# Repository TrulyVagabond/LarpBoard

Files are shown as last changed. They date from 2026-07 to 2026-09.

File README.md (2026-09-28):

[][contributors-url]
[][forks-url]
[][stars-url]
[][issues-url]
[][license-url]

<br />
<div align="center">
  
  <h3 align="center">LarpBoard</h3>

  <p align="center">
    A Keyboard for Larpers
    <br />
    <br />
    <a href="https://github.com/TrulyVagabond/LarpBoard/blob/main/JOURNAL.md">Journal</a>
    &middot;
    <a href="https://github.com/TrulyVagabond/LarpBoard/issues">Report Bug</a>
    &middot;
    <a href="https://github.com/TrulyVagabond/LarpBoard/issues">Request Feature</a>
  </p>
</div>

## What is LarpBoard?

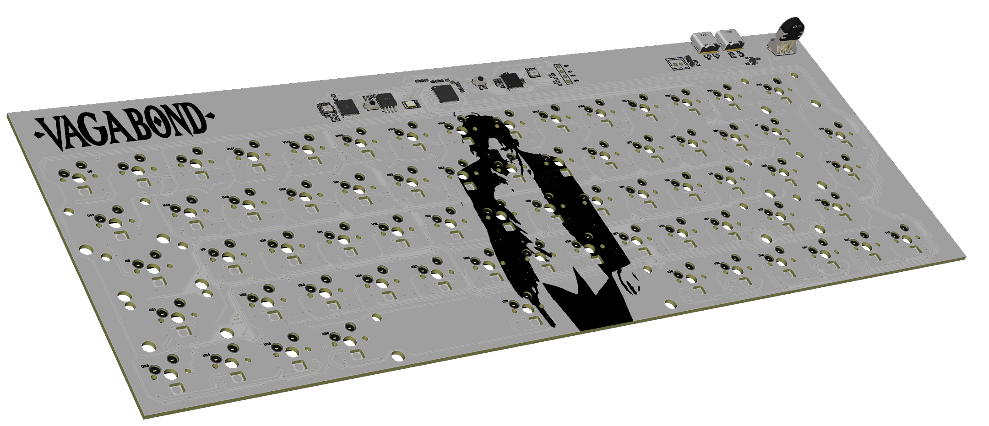
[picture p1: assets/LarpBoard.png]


LarpBoard is a 65% Keyboard Designed for Professional Larpers. Keep in mind tho that you will not get ANY girls if you have this (More MEN attraction). Build and Use this at your own Risk. Well Lets Talk about why this Keyboard will be unique and better than other Low Level Keyboards. This Keyboard Includes Kailh Hot-Swap Sockets and RGB LEDs. A 0.9inch OLED Display for CMatrix. An NFC reader cuz why not, a solenoid for sound, 2 USB-C Ports, a USB Hub Chip and the Main MCU RP2040.

### Schematics:

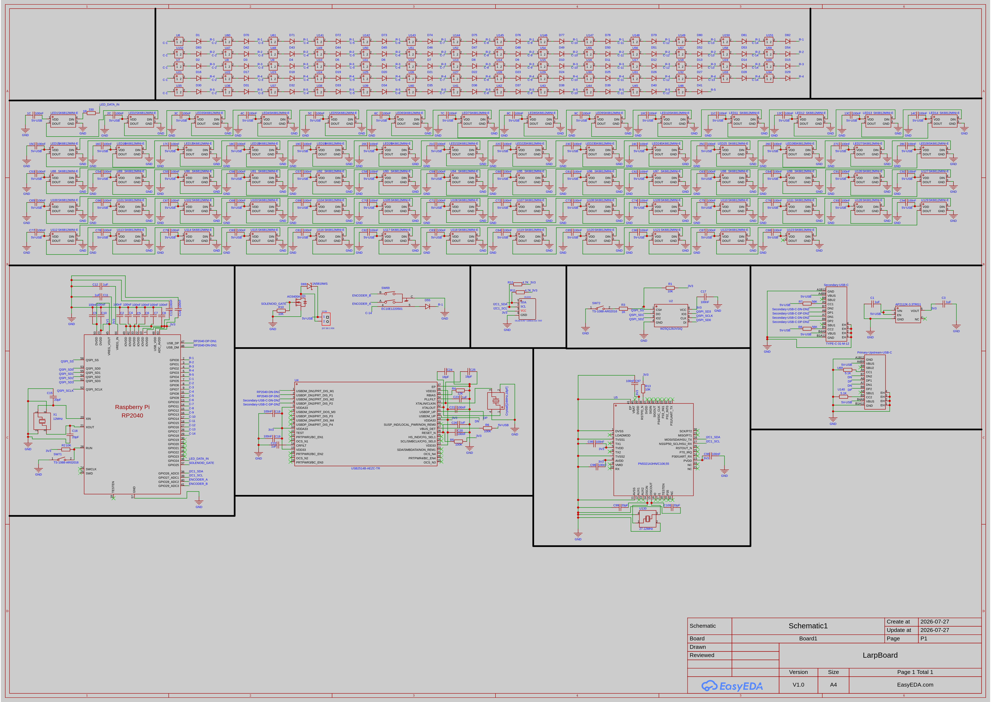
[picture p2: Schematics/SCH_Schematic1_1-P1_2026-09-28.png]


### PCB Wiring: 

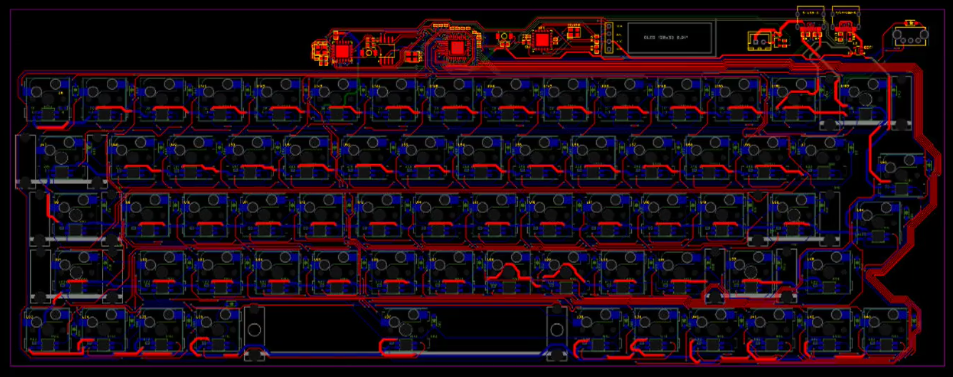
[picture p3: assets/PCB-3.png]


### Case Render:

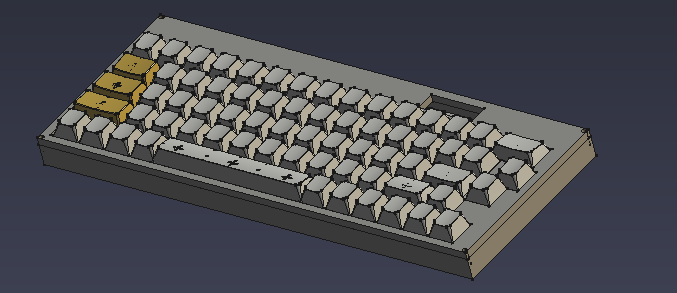
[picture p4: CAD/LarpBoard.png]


### Built With

* [][EasyEDA-url]
* [][FreeCAD-url]

## Getting Started

To get Your own LarpBoard, you need three things.

- PCB
- 3d-Printed Enclosure
- Money

### Ordering the PCB

1. Navigate to the Gerber Files in the **"Gerber"** Folder. 

2. Download the ".zip" File

3. Upload this '.zip' file to a custom PCB manufacturer (Like PCBWay, OSH Park or JLCPCB) or not if you're going to solder on your own

4. Standard Manufacturing Settings (1.6mm thickness) work Perfectly for this Board.

### 3D Printing the Enclosure

1. Navigate to the **"CAD"** folder.

2. Download the .Step File and Upload it into your Desired 3D slicing Software.

## Bills Of Materials (BOM)

| Qty | Component | Designator | Direct Source Link | Unit Cost | Total |
| :--- | :--- | :--- | :--- | :--- | :--- |
| 87 | 100nF Capacitor | 1C, 2C, 3C, 4C... | [LCSC Catalog](https://www.lcsc.com/product-detail/C307380.html?s_z=n_q_0201%2520100nF) | $0.0061 | $0.53 |
| 1 | 330Ω Resistor | 1R | [LCSC Catalog](https://www.lcsc.com/product-detail/C105881.html?s_z=n_q_t_0603%2520330%2520ohm) | $0.0049 | $0.0049 |
| 7 | 1uF Capacitor | C1, C3, C11, C12... | [LCSC Catalog](https://www.lcsc.com/product-detail/C76930.html?s_z=n_q_0201%25201uF) | $0.0500 | $0.35 |
| 4 | 20pF Capacitor | C15, C16, C99, C100 | [LCSC Catalog](https://www.lcsc.com/product-detail/C71879.html?s_z=n_q_0201%252020pF) | $0.0014 | $0.0056 |
| 2 | 18pF Capacitor | C24, C25 | [LCSC Catalog](https://www.lcsc.com/product-detail/C913481.html?s_z=n_q_0201%252018pF) | $0.0046 | $0.0092 |
| 1 | 27.12MHz Crystal | Crystal | [JLCPCB Catalog](https://jlcpcb.com/partdetail/JLCPCBAssembly-2712MHz/C9900013048) | $0.1000 | $0.10 |
| 100 | 1N4148W T4 SOD-123 diodes | D1, D2, D3, D4... | [AliExpress Link](https://www.aliexpress.com/item/1005010653199938.html) | $0.0180 | $1.80 |
| 1 | 1N5819WS Diode | D69 | [LCSC Product Page](https://jlcpcb.com/partdetail/GuangdongHottech-1N5819WS/C191023) | $0.0150 | $0.015 |
| 68 | SK6812MINI-E LED | LED1, LED2, LED3... | [JLCPCB](https://jlcpcb.com/partdetail/OPSCOOptoelectronics-SK6812MINIE/C5149201) | $0.0800 | $5.44 |
| 1 | PN5321A3HN/C106;55 | NFC | [LCSC Product Page](https://jlcpcb.com/partdetail/NXPSemicon-PN5321A3HN_C10655/C28925) | $13.3500 | $13.35 |
| 1 | OLED 0.91" 128X32 I2C | OLED1 | [AliExpress Search](https://www.aliexpress.com/item/1005004563827538.html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) | $1.5000 | $1.50 |
| 2 | TYPE-C-31-M-12 Port | P/UP-USB-C, S-USB-C | [LCSC Product Page](https://jlcpcb.com/partdetail/Korean_HropartsElec-TYPE_C_31_M12/C165948) | $0.1300 | $0.26 |
| 1 | AO3400A MOSFET | Q1 | [LCSC Product Page](https://jlcpcb.com/partdetail/Alpha_OmegaSemicon-AO3400A/C20917) | $0.0800 | $0.08 |
| 4 | 10KΩ Resistor | R1, R2, R10, R13 | [LCSC Catalog](https://www.lcsc.com/product-detail/C98220.html?s_z=s_q_t_0603%252010K%25CE%25A9) | $0.0035 | $0.014 |
| 1 | 1KΩ Resistor | R3 | [LCSC Catalog](https://www.lcsc.com/product-detail/C5362357.html?s_z=n_q_0603%25201K) | $0.0033 | $0.0033 |
| 1 | 12KΩ Resistor | R4 | [LCSC Catalog](https://www.lcsc.com/product-detail/C2906989.html?s_z=n_q_t_0603%252012K%25CE%25A9) | $0.0023 | $0.0023 |
| 2 | 100KΩ Resistor | R5, R6 | [LCSC Catalog](https://www.lcsc.com/product-detail/C14675.html?s_z=n_q_t_0603%2520100K%25CE%25A9) | $0.0230 | $0.046 |
| 2 | 56KΩ Resistor | R7, R8 | [LCSC Catalog](https://www.lcsc.com/product-detail/C2907053.html?s_z=n_q_t_0603%252056K%25CE%25A9) | $0.0025 | $0.005 |
| 2 | 4.7KΩ Resistor | R11, R12 | [LCSC Catalog](https://www.lcsc.com/product-detail/C99782.html?s_z=n_q_t_0603%25204.7K%25CE%25A9) | $0.0040 | $0.008 |
| 1 | EC10E1220501 Encoder | SW69 | [JLCPCB](https://jlcpcb.com/partdetail/ALPSALPINE-EC10E1220501/C160889) | $9.2400 | $9.24 |
| 2 | TS-1088-AR02016 Switch | SW71, SW72 | [LCSC Product Page](https://jlcpcb.com/partdetail/XUNPU-TS_1088AR02016/C720477) | $0.0500 | $0.10 |
| 1 | RP2040 Microcontroller | U1 | [LCSC Product Page](https://jlcpcb.com/partdetail/RaspberryPi-RP2040/C2040) | $0.9900 | $0.99 |
| 1 | W25Q128JVSIQ Flash | U2 | [LCSC Product Page](https://jlcpcb.com/partdetail/WinbondElec-W25Q128JVSIQ/C97521) | $2.5500 | $2.55 |
| 1 | AP2112K-3.3TRG1 LDO | U3 | [LCSC Product Page](https://jlcpcb.com/partdetail/DiodesIncorporated-AP2112K_33TRG1/C51118) | $0.1700 | $0.17 |
| 1 | USB2514B-AEZC-TR Hub | U4 | [LCSC Product Page](https://jlcpcb.com/partdetail/MicrochipTech-USB2514B_AEZCTR/C16251) | $1.8000 | $1.80 |
| 50 | kailh choc v2 hotswap sockets | U6, U7, U8, U9... | [AliExpress Link](https://www.aliexpress.com/item/1005006610506123.html) | $0.1160 | $5.80 |
| 6 | CHERRYMX STAB 2U | U62, U64, U65... | [AliExpress Search](https://www.aliexpress.com/item/1005007212869086.html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) | $0.3500 | $2.10 |
| 1 | STAB 6.25U | U63 | [AliExpress Search](https://www.aliexpress.com/item/1005004229140548.html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) | $0.3500 | $0.35 |
| 2 | 5.1KΩ Resistor | U69, U140 | [LCSC Catalog](https://www.lcsc.com/product-detail/C2907044.html?s_z=n_q_t_0603%25205.1K%25CE%25A9) | $0.0021 | $0.0042 |
| 1 | JST_XH CONNECTOR | U139 | [AliExpress Link](https://www.aliexpress.com/item/1005006439646258.html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) | $0.0500 | $0.05 |
| 1 | X322512MLB4SI Crystal | X1 | [LCSC Product Page](https://jlcpcb.com/partdetail/114205-X322512MLB4SI/C112971) | $0.1100 | $0.11 |
| 1 | Crystal/[24MHz,18pF] | X2 | [LCSC Catalog](https://jlcpcb.com/partdetail/3481712-Crystal_24MHz_18pF/C9900014727) | $0.0021 | $0.0021 |
| 50 | 8mm m3 screws | Case Hardware | [AliExpress Link](https://www.aliexpress.com/item/1005005618746295.html) | $0.0570 | $2.85 |
| 30 | 8mm m3 screw standoffs | Case Hardware | [AliExpress Link](https://www.aliexpress.com/item/1005002952338852.html) | $0.1350 | $4.05 |
| 5 | the pcb | (JLCPCB Assembly) | JLCPCB | $3.1600 | $15.80 |
| **-** | **HARDWARE TOTAL** | | | | **$69.49** |

## Assembling LarpBoard

- **PCB Assembly:**

   1. You can Either Order the PCB pre-soldered from Manufacturers. or you can Solder on your own. See the PCB layout for Soldering. 

- **Flashing the Firmware:**

  1. Unplug your keyboard's USB cable.

  2. Press and hold the physical BOOT button (connected to RP2040 pin 43)
  
  3. While holding the button, insert the USB-C cable into your computer, then release the button. 

  4. Your OS will mount the RP2040 as a USB mass storage drive called RPI-RP2

  5. Drag and drop the "vagabond_default.uf2" file from the Firmware directory,  directly into the RPI-RP2 drive folder.

  6. The drive will immediately unmount automatically, the RP2040 will reboot, and your computer will recognize it as a functioning USB HID keyboard.

- **Case Assembly:**

  1. 3D Print the Enclosure with the Specified Settings Above.

  2. You Must 3D print the Front and Back Shell Separately.

  3. Use **M3 Screws** to Screw in everything, The Front Shell and Back Shell. 

  4. Your **LarpBoard** is Ready to Use.

## Special Thanks:

- **FreeCAD** for the Amazing 3D Modeling Free Software.

- **EasyEDA** for the Amazing PCB Designing Free Software.

- **Hack Club** for making me Motivated enough to make this haha.

## License

This Project is Distributed Under MIT License. Check License.txt for More Information.

<!-- MARKDOWN LINKS & IMAGES -->
[contributors-shield]: https://img.shields.io/github/contributors/TrulyVagabond/Vashtastic.svg?style=for-the-badge
[contributors-url]: https://github.com/TrulyVagabond/Vashtastic/graphs/contributors

[forks-shield]: https://img.shields.io/github/forks/TrulyVagabond/Vashtastic.svg?style=for-the-badge
[forks-url]: https://github.com/TrulyVagabond/Vashtastic/network/members

[stars-shield]: https://img.shields.io/github/stars/TrulyVagabond/Vashtastic.svg?style=for-the-badge
[stars-url]: https://github.com/TrulyVagabond/Vashtastic/stargazers

[issues-shield]: https://img.shields.io/github/issues/TrulyVagabond/Vashtastic.svg?style=for-the-badge
[issues-url]: https://github.com/TrulyVagabond/Vashtastic/issues

[license-shield]: https://img.shields.io/github/license/TrulyVagabond/Vashtastic.svg?style=for-the-badge
[license-url]: https://github.com/TrulyVagabond/Vashtastic/blob/main/LICENSE

[EasyEDA]: https://img.shields.io/badge/EasyEDA-0177D7?style=for-the-badge
[EasyEDA-url]: https://easyeda.com/

[FreeCAD]: https://img.shields.io/badge/FreeCAD-2D9CDB?style=for-the-badge&logo=freecad&logoColor=white
[FreeCAD-url]: https://www.freecad.org/

<br>

###### Note: A.I was only used for Research Purposes.

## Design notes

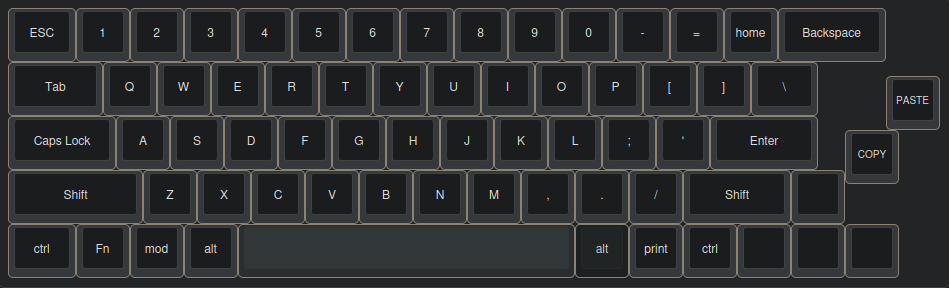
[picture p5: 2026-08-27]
assets/Keyboard-Design.png

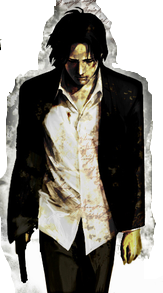
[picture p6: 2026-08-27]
assets/Kenzo-Tenma.png

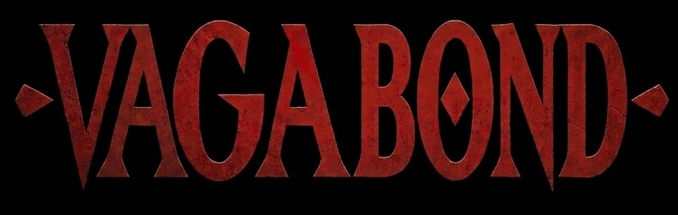
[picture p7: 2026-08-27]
assets/Vagabondd.png

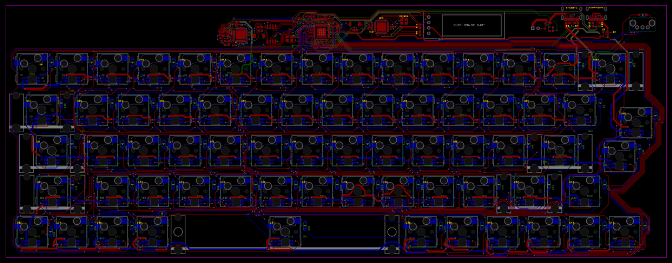
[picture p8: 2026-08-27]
PCB/Finished.png

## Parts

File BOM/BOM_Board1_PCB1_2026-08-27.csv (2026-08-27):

No. | Quantity | Comment | Designator | Footprint | Value | Manufacturer Part | Manufacturer | Supplier Part | Supplier | Name | LCSC Stock | LCSC Price
1 | 87 | 100nF | 1C,2C,3C,4C,5C,6C,7C,8C,9C,10C,11C,12C,13C,14C,15C,16C,17C,18C,19C,20C,21C,22C,23C,24C,25C,26C,27C,28C,C2,C4,C5,C6,C7,C8,C9,C10,C13,C14,C17,C18,C19,C20,C21,C53,C54,C55,C56,C57,C58,C59,C60,C61,C62,C63,C64,C65,C66,C67,C68,C69,C70,C71,C72,C73,C74,C75,C76,C77,C78,C79,C80,C81,C82,C83,C84,C85,C86,C87,C88,C91,C92,C93,C94,C95,C96,C97,C98 | C0201 | 100nF |  |  |  |  | 100nF |  | 4.0362
2 | 1 | 330 | 1R | R0603 | 330 |  |  |  |  | 330 |  | 4.0362
3 | 7 | 1uF | C1,C3,C11,C12,C22,C23,C26 | C0201 | 1uF |  |  |  |  | 1uF |  | 4.0362
4 | 4 | 20pF | C15,C16,C99,C100 | C0201 | 20pF |  |  |  |  | 20pF |  | 4.0362
5 | 2 | 18pF | C24,C25 | C0201 | 18pF |  |  |  |  | 18pF |  | 4.0362
6 | 1 | 27.12MHz | Crystal | CRYSTAL-SMD_4P-L3.2-W2.5-BL |  | 27.12MHz |  | C9900013048 | LCSC | 27.12MHz
7 | 69 | 1N4148W-7-F | D1,D2,D3,D4,D5,D6,D7,D8,D9,D10,D11,D12,D13,D14,D15,D16,D17,D18,D19,D20,D21,D22,D23,D24,D25,D26,D27,D28,D29,D30,D31,D32,D33,D34,D35,D36,D37,D38,D39,D40,D41,D42,D43,D44,D45,D46,D47,D48,D49,D50,D51,D52,D53,D54,D55,D70,D71,D72,D73,D74,D75,D76,D77,D78,D79,D80,D81,D82,D83 | SOD-123_L2.7-W1.6-LS3.7-RD-1 |  | 1N4148W-7-F | DIODES(美台) | C83528 | LCSC | 1N4148W-7-F
8 | 1 | 1N5819WS | D69 | SOD-323_L1.8-W1.3-LS2.5-RD |  | 1N5819WS | Hottech(合科泰) | C191023 | LCSC | 1N5819WS
9 | 68 | SK6812MINI-E | LED1,LED2,LED3,LED4,LED5,LED6,LED7,LED8,LED9,LED10,LED11,LED12,LED13,LED14,LED15,LED16,LED17,LED18,LED19,LED20,LED21,LED22,LED23,LED24,LED25,LED26,LED27,LED28,U88,U89,U90,U91,U92,U93,U94,U95,U96,U97,U98,U99,U100,U101,U102,U103,U104,U105,U106,U107,U108,U109,U110,U111,U112,U113,U114,U115,U116,U117,U118,U119,U120,U121,U122,U123,U126,U127,U128,U129 | LED-SMD_L3.2-W2.8-P1.50-LS5.8-TR-EH |  | SK6812MINI-E |  | C9900001298 | LCSC | SK6812MINI-E
10 | 1 | PN5321A3HN/C106;55 | NFC | QFN-40_L6.0-W6.0-P0.50-BL-EP4.1 |  | PN5321A3HN/C106;55 |  | C691468 | LCSC | PN5321A3HN/C106;55
11 | 1 | OLED 0.91\" 128X32 I2C THT | OLED1 | OLED 0.91\" 128X32 I2C THT |  |  |  |  |  | OLED 0.91\" 128X32 I2C THT
12 | 2 | TYPE-C-31-M-12 | P/UP-USB-C,S-USB-C | USB-C_SMD-TYPE-C-31-M-12_1 |  | TYPE-C-31-M-12 | 韩国韩荣 | C165948 | LCSC | TYPE-C-31-M-12
13 | 1 | AO3400A | Q1 | SOT-23-3_L2.9-W1.3-P1.90-LS2.4-BR |  | AO3400A | HUASHUO(华朔) | C700953 | LCSC | AO3400A
14 | 4 | 10K | R1,R2,R10,R13 | R0603 | 10K |  |  |  |  | 10K |  | 4.0362
15 | 1 | 1K | R3 | R0603 | 1K |  |  |  |  | 1K |  | 4.0362
16 | 1 | 12K | R4 | R0603 | 12K |  |  |  |  | 12K |  | 4.0362
17 | 2 | 100K | R5,R6 | R0603 | 100K |  |  |  |  | 100K |  | 4.0362
18 | 2 | 56K | R7,R8 | R0603 | 56K |  |  |  |  | 56K |  | 4.0362
19 | 2 | 4.7K | R11,R12 | R0603 | 4.7K |  |  |  |  | 4.7K |  | 4.0362
20 | 1 | EC10E1220501 | SW69 | SW-TH_EC10EXXXXXXX |  | EC10E1220501 | ALPSALPINE(阿尔卑斯阿尔派) | C160889 | LCSC | EC10E1220501
21 | 2 | TS-1088-AR02016 | SW71,SW72 | SW-SMD_L3.9-W3.0-P4.45 |  | TS-1088-AR02016 | XUNPU(讯普) | C720477 | LCSC | TS-1088-AR02016
22 | 1 | RP2040 | U1 | QFN-56_L7.0-W7.0-P0.40-TL-EP4.0 |  | RP2040 | Raspberry Pi(树莓派) | C2961140 | LCSC | RP2040
23 | 1 | W25Q128JVSIQ | U2 | SOIC-8_L5.3-W5.3-P1.27-LS8.0-BL |  | W25Q128JVSIQ | Winbond(华邦) | C97521 | LCSC | W25Q128JVSIQ
24 | 1 | AP2112K-3.3TRG1 | U3 | SOT-23-5_L2.9-W1.6-P0.95-LS2.8-BR |  | AP2112K-3.3TRG1 | TECH PUBLIC(台舟) | C23380830 | LCSC | AP2112K-3.3TRG1
25 | 1 | USB2514B-AEZC-TR | U4 | VQFN-36_L6.0-W6.0-P0.50-BL-EP |  | USB2514B-AEZC-TR | MICROCHIP(美国微芯) | C16251 | LCSC | USB2514B-AEZC-TR
26 | 68 | CPG135001S30 | U6,U7,U8,U9,U10,U11,U12,U13,U14,U15,U16,U17,U18,U19,U20,U21,U22,U23,U24,U25,U26,U27,U28,U29,U30,U31,U32,U33,U34,U35,U36,U37,U38,U39,U40,U41,U42,U43,U44,U45,U46,U47,U48,U49,U50,U51,U52,U53,U54,U55,U56,U57,U58,U59,U60,U61,U141,U142,U143,U144,U145,U146,U147,U148,U149,U150,U151,U152 | PCM_Switch_Keyboard_Hotswap_Kailh:SW_Hotswap_Kailh_MX_Plated_1.00u |  | CPG135001S30 | Kailh(凯华) | C5333465 | LCSC | CPG135001S30
27 | 6 | CHERRYMX STABILIZER 2U | U62,U64,U65,U66,U67,U68 | CHERRYMX STABILIZER 2U |  |  |  |  |  | CHERRYMX STABILIZER 2U
28 | 1 | STAB 6.25U | U63 | CHERRY MX 6.25U STABILIZER |  |  | Bolt Industries |  |  | STAB 6.25U
29 | 2 | 5.1K | U69,U140 | R0603 | 5.1K |  |  |  |  | 5.1K |  | 4.0362
30 | 1 | JST XH 2 PIN | U139 | JST_2-PIN_2.54MM |  | JST_XH CONNECTOR |  |  |  | JST XH 2 PIN
31 | 1 | 12MHz | X1 | CRYSTAL-SMD_4P-L3.2-W2.5-BL-1 | 12MHz | X322512MLB4SI | YXC(扬兴晶振) | C112971 | LCSC | 12MHz
32 | 1 | Crystal/[24MHz,18pF] | X2 | CRYSTAL-SMD_4P-L3.2-W2.5-BL |  | Crystal/[24MHz,18pF] |  | C9900014727 | LCSC | Crystal/[24MHz,18pF]

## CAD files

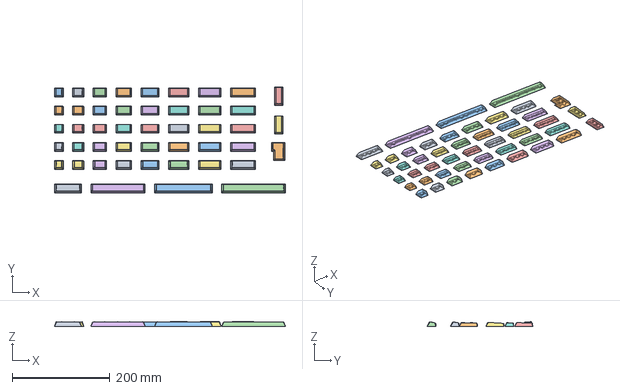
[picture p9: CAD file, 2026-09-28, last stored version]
CAD/CHERRYMX CAD_CAM KEYCAPS.stp
471.6 x 215.6 x 9.30 mm

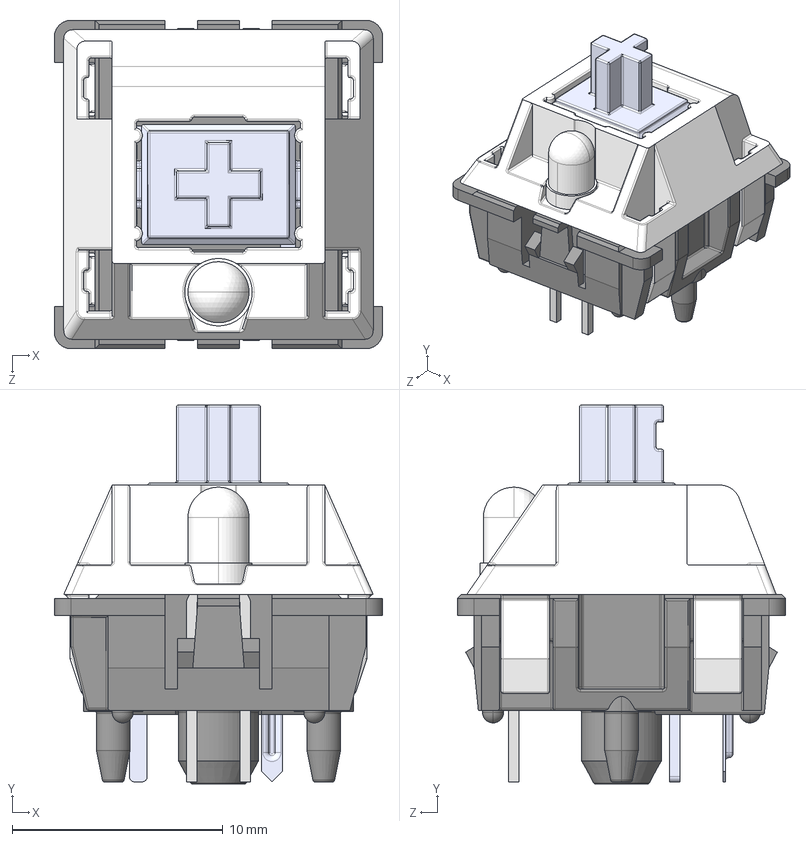
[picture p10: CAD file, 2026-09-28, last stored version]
CAD/Cherry MX.STEP
15.6 x 18.0 x 15.6 mm
Bottom
Pulsador
Top
Pieza5^Cherry MX
Pin1
Pin2
Led 3mm_trans

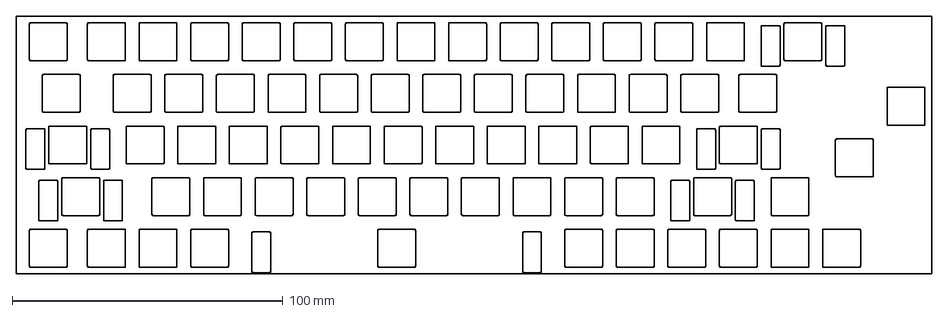
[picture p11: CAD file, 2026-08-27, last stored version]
CAD/SwitchPlate.dxf
338.1 x 95.2 mm

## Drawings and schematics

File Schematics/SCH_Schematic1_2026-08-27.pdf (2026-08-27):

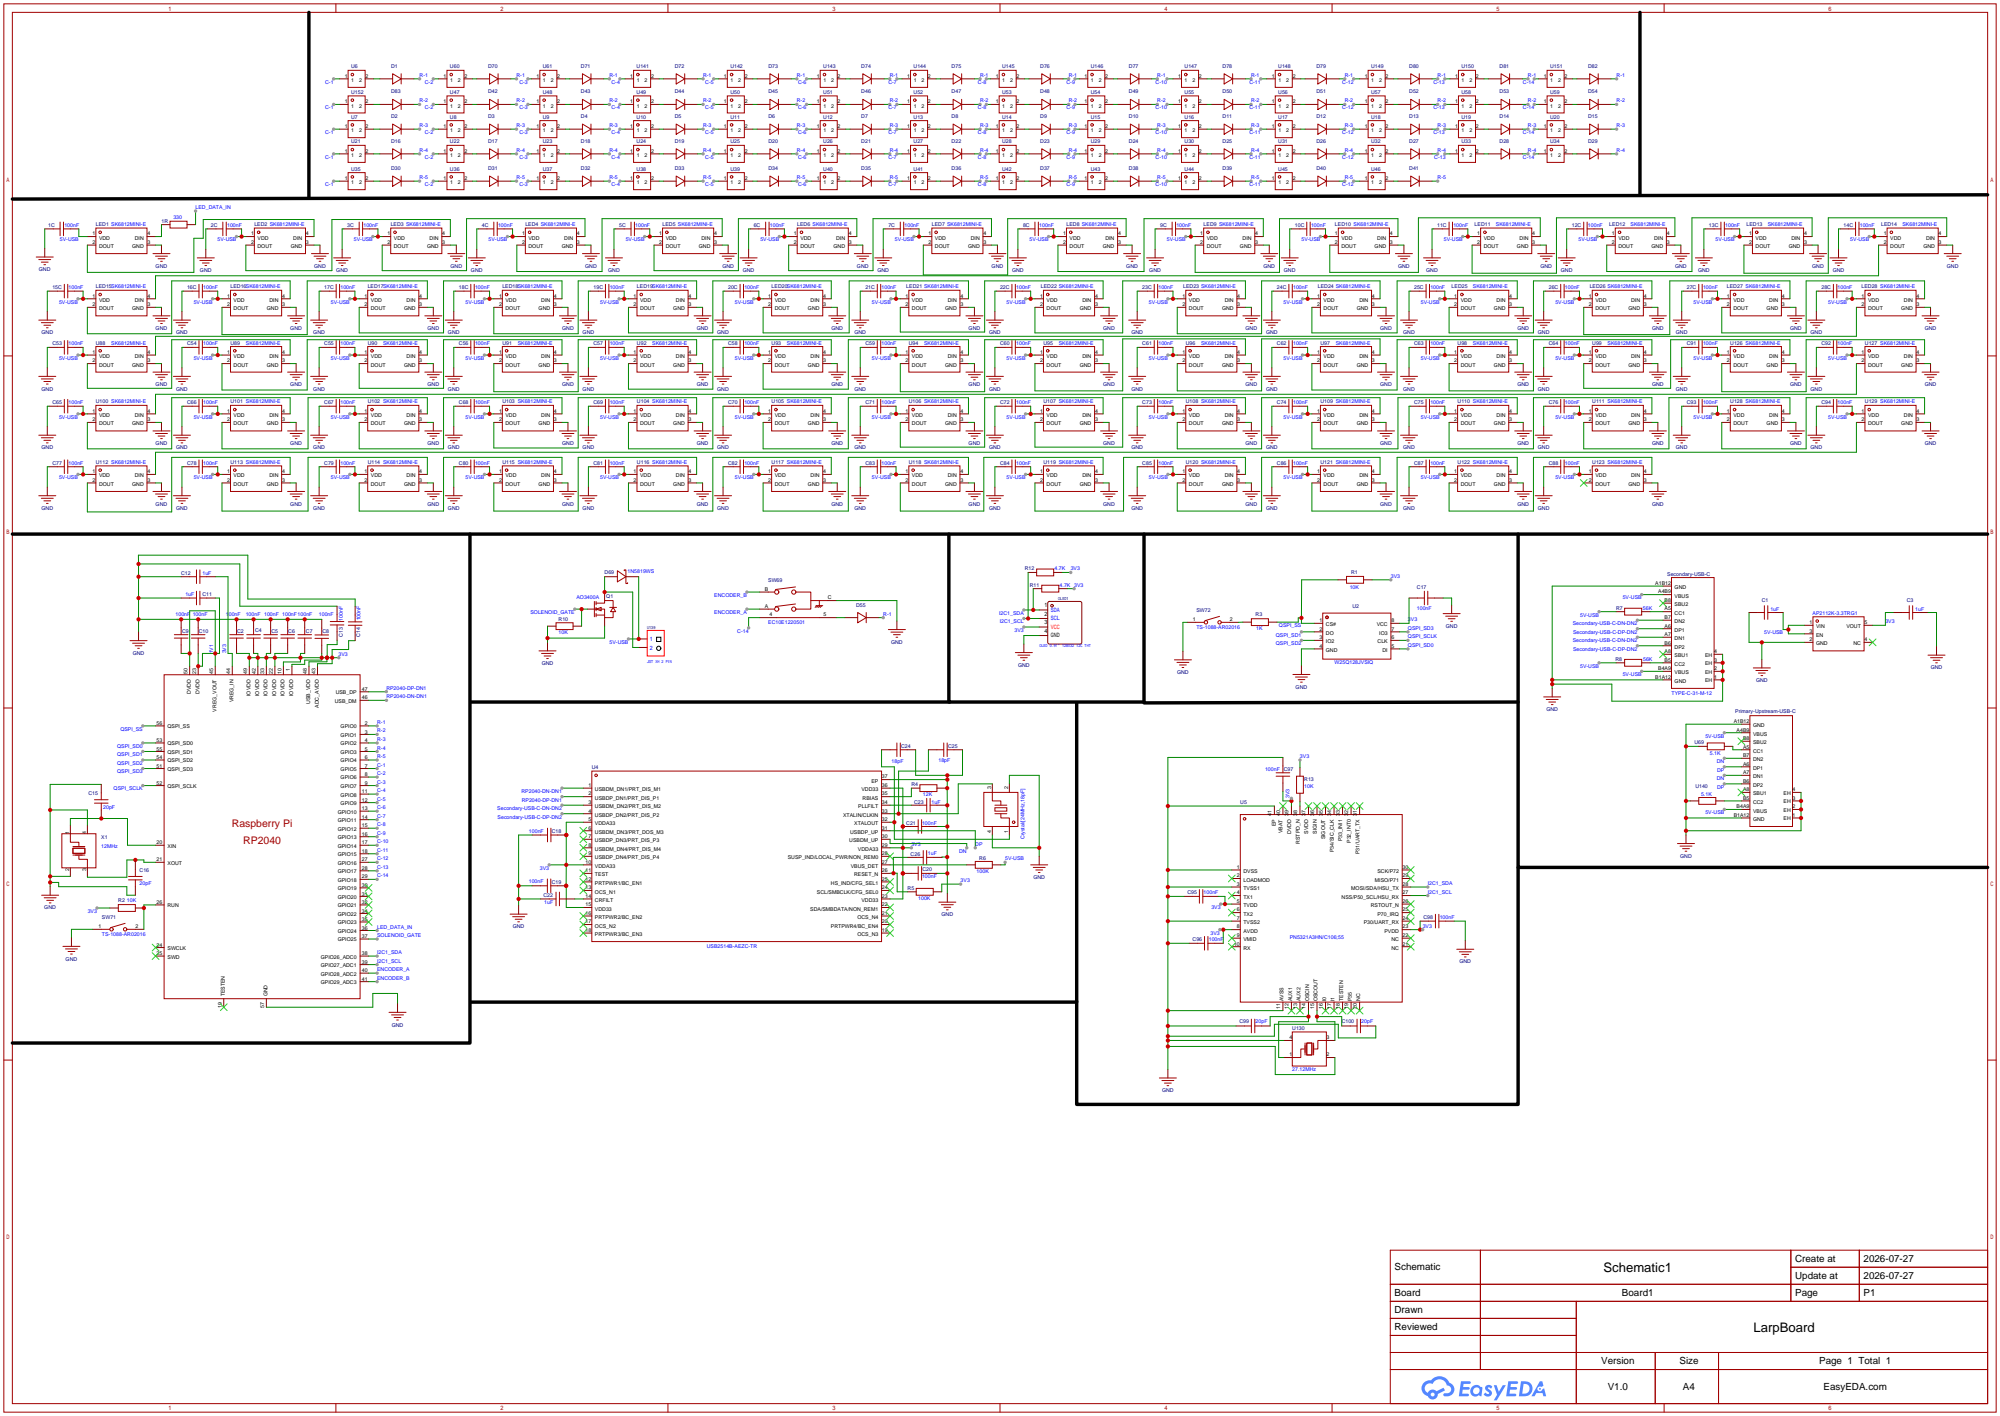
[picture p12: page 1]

Schematic | Schematic1 | Create at | 2026-07-27

Update at | 2026-07-27

Board | Board1 | Page | P1
Drawn | | LarpBoard
Reviewed

Version | Size | Page 1 Total 1

V1.0 | A4 | EasyEDA.com

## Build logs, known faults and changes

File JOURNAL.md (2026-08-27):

# LarpBoard: A Keyboard for Larpers.

## What is Larp?

Larp Means to Speak About or Show Affection to Something You don't know Anything About. Just following the Trend. Not having a single Clue about the Genre. Common Larpers are people who Have Not Played a Single Devil May Cry Games but Seem to "Like" it, and someone who hasn't watched a single episode of "Serial Experiment Lain" but uses the Main Character as a pfp (Myself Included).

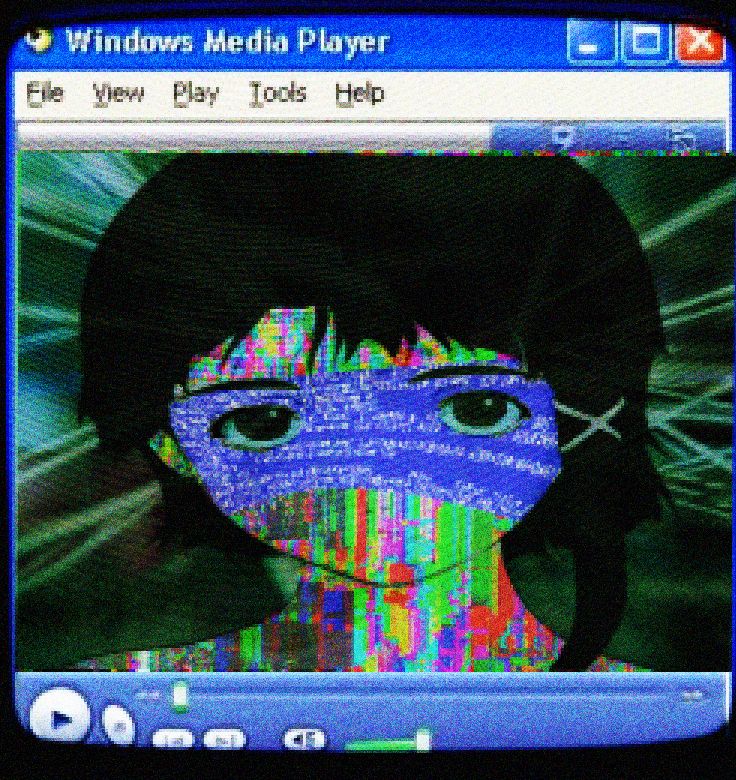
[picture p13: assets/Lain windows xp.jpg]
Let's all love lain


 and on the rise right now are the **Linux Larpers**, who run Cmatrix in the terminal and think that they are some kind of hackers or something (Me asf).

Well Larping is a Skill in itself, and there are levels to ts. So thats why I'm making this LarpBoard, to Enhance the Experience of Larpers and Helping them achieve True Larping-ness.

## LarpBoard

LarpBoard is a 65% Keyboard Designed for Professional Larpers. Keep in mind tho that you will not get ANY girls if you have this (More MEN attraction). Build and Use this at your own Risk. Well Lets Talk about why this Keyboard will be unique and better than other Low Level Keyboards. This Keyboard Includes Kailh Hot-Swap Sockets and RGB LEDs. A 0.9inch OLED Display for CMatrix. A rollable Volume Knob cuz why not, an NFC reader cuz why not, a solenoid for sound, 2 USB-C Ports, a USB Hub Chip and the Main MCU RP2040.

Well these are the Names and Details of the Components in Detail.

- **MCU: RP2040:**

This is the Main Chip which Makes everything Work Together, This Chip Requires 3.3V so we need another thing to make it work, which is.... you guessed it

- **LDO: AP2112K-3.3TRG1:**

This is the Stuff that eats 5V from the USB-C and converts it into 3V for everything on my LarpBoard PCB, like literally everything. There are other pretty popular LDO's like AMS1117 etc. We also need A Flash Memory for RP2040.

- **FLASH: W25Q128JVSIQ:**

This is a 16MB (128M-bit) SPI Flash memory chip, because RP2040 Doesn't have it's own internal Storage, i have to use this.

- **MCU Clock: 12MHz Crystal Oscillator**

This Provides the Pulse for when the RP2040 needs to work etc, i also added 2 20pF Capacitors, because that's something you need to do apparantly

- **Buttons: TS-1088-AR02016:**

Need these buttons to reset and boot the RP2040. Thats all, i mean what did you expect a button to do.

- **USB Ports: TYPE-C-31-M-12:**

I'm Using two of these, one for Upstream and one for obviously Downstream. It's always fun to add USB-C, maybe i'll add 10 next who knows, wait i got another idea. peak, see you with another project after arcana.

- **Switches: Kailh Choc hotswap sockets:**

Added 68 of these, i heard that these are pretty good and low profile.

- **Diodes: 1N4148**

Used this because this helps prevent Ghosting when you press multiple keys at once, which is peak. used 68 of these too.

- **Addressable LED's: SK6812MINI-E:**

These are RGB Addressable LED's which are placed directly under the keycaps, so it shines the light from beneath. Used 68 of these too, also added the required resistors and capacitors. I had to add 68 100nF Decoupling Capacitors to prevent color flikering and power drops.

- **USB-HUB: USB2514B-AEZC-TR:**

A dedicated 2.0 Hub chip, it splits the board's main USB connection internally to route data to the secondary USB-C port. and also other internal peripherals

- **NFC/RFID Controller: PN5321A3HN/C106,55:**

So you can swipe your cards or anything that can be read by NFC right on your keyboard. I had to use a 27.12MHz Crystal Oscillator.

- **OLED Display: OLED-0.91-128x32-I2C-THT:**

A 0.91 Inch OLED screen running on I2C to help you larp better by showing Cmatrix or typing speed (if thats your thing).

- **Rotary Encoder: EC10E1220501:**

A sideways, rollable Volume knob. Cuz why not.

### These are all the Components.

## 19-July-2026 

### Schematics:

Started Working on the Schematics and placed all the components and their respective capacitors and resistors. I also had alot of problems as always, the first problem was finding the right footprints and symbols for the Sockets and LED's. I had to use the User-Contributed Footprints. 

**Kailh Hot-Swap Sockets Problem:**

Even after that, i realized later that the guy who made the footprint, made the pads and everything stay on the bottom layer, so EasyEDA shows that its on the top layer, even tho it isn't. and that wasted alot of my time to figure out what was wrong. i just had to edit the footprint to make the pads and everything stay on the top layer and fixed the 3D model etc too.

Wiring everything was a pain because i had so many different things to lookout for, had to wire everything of the RP2040 to every other component. The Process was simple tho because I just had to think of how everything powers. 5V comes from the Computer etc through the USB-C Port and first gets into the LDO, which converts that 5V into a smooth and stable 3.3V for all the other components, I then just wire everything from the LDO to everything else. simple logic. But since I had SOOOOOO many components, this took ALOT of time, well after wiring everything, here's how it looks.

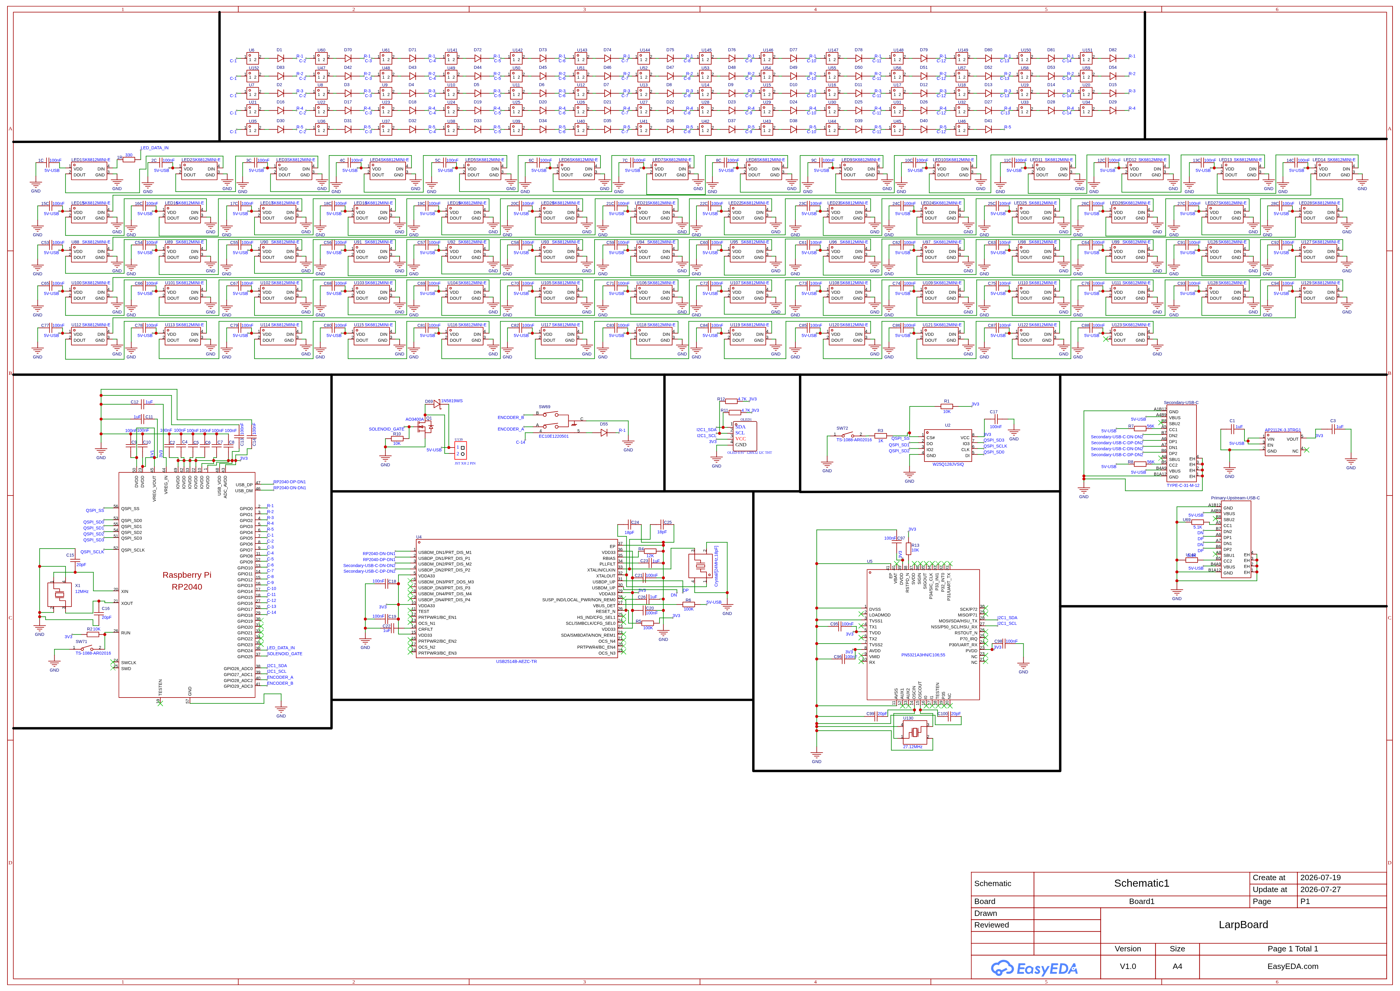
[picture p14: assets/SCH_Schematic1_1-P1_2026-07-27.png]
Finished Schematic


[Lapse-Recording](https://lapse.hackclub.com/timelapse/jaFWriPHnn3V)

## 26-July-2026 - 29-July-2026

### PCB Design:

Took a HUGE break in between cuz i had to buy the passport and do all that shi, it is such a pain to go to the government offices etc but Alhamdulillah, i got everything successfully tho. I also had other stuff to do and i was tired thats why i didn't write much in the journal. I started working on the PCB design and it SOOO laggy, i had to download the easyEDA software. and thankfully it was on linux but man it still gives errors and stuff sometimes. but it was working smoothly. I started by placing the components and its capacitors and resistors as close as possible to each other. after that i started routing everything. but there was a problem, all the leds and sockets showed DRC errors, because the PADs and stuff were too close to each but thats how the footprints are for sockets and LEDs so i had to change the Design rule to make it not show errors. Here is how everything was placed:

- **Placement of the Sockets:**
Well obviously the Sockets were placed 1 Unit away from each other which is the size of a normal Keycaps. well my sockets footprint had a box around it, which shows how much area each key takes, so it was pretty easy to place and design the keyboard, my keyboard includes 68 keys, which is all the letters and the arrow keys, i also added two different keys which i will use for copy and pasting. this will be such a peak keyboard man. After placing all the Sockets, this is how it looked:

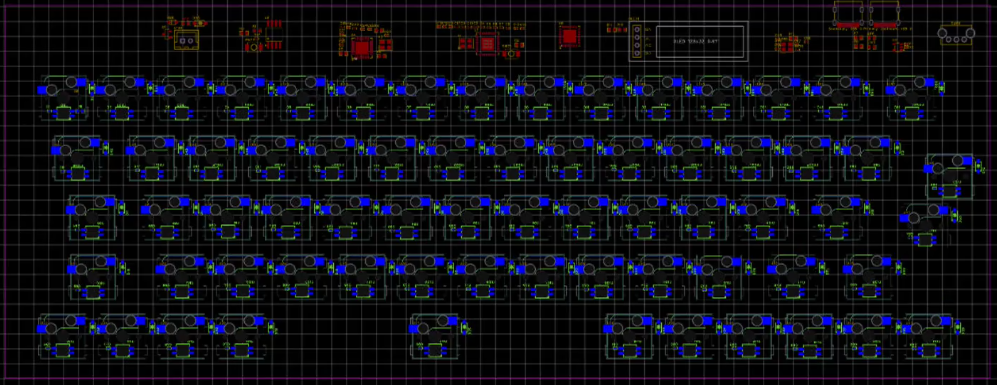
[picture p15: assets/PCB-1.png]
PCB-1


Now i just had to wire all of them together which took ALOTT of time, i worked like 10+ hours a day for this. and if i still can't go to arcana then i would cry man. well i started wiring the sockets to the diodes first and then sockets to sockets. after that was done, i wired the LED's together in a daisy chain type stuff. i also had to add stabalizers on the keys which took 2 units or more. i found the footprint for the stablizer and placed it according to the center hole of the key. Here's how it looks now:

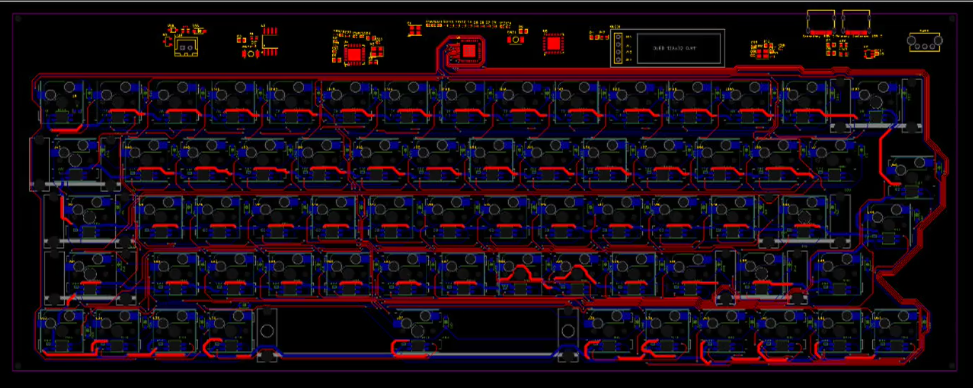
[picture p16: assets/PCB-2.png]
PCB-2


I'm pretty happy with the wiring as of now and really like how it is looking. Now i have to wire all the other components and then make a ground plane to finish the PCB. Here's how it looks after wiring everything, this took another 10 hours btw:



idk about you but this looks so good to me man. Im finally done with everything on the PCB and i can finally ship this now. I also need to write the readme tho.

[Lapse-Recording-1](https://lapse.hackclub.com/timelapse/z0EAE3T4yNss)
[Lapse-Recording-2](https://lapse.hackclub.com/timelapse/z0EAE3T4yNss)
[Lapse-Recording-3](https://lapse.hackclub.com/timelapse/z0EAE3T4yNss)

## 26-August-2026 - 27-August-2026

### Designing the PCB:

Ofc I couldn't have just left it like that, i had to make it look good. Well I did just that and Added some Silkscreen Art to the PCB. Here's how it Looks.

LarpBoard

Used the Monster Anime for Inspiration this time, ah man it is soooo peak. I can finally submit it now.

[Lapse-Recording](https://lapse.hackclub.com/timelapse/z0EAE3T4yNss)
[Lapse-Recording](https://lapse.hackclub.com/timelapse/z0EAE3T4yNss)

***//See you Space Cowboy***

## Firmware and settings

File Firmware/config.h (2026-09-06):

#pragma once

#define DEBOUNCE 5

#define ENCODER_RESOLUTION 4

#define RGBLIGHT_LED_COUNT 68
#define RGBLIGHT_LIMIT_VAL 180
#define RGBLIGHT_HUE_STEP 8
#define RGBLIGHT_SAT_STEP 8
#define RGBLIGHT_VAL_STEP 8
#define RGBLIGHT_SLEEP

#define I2C_DRIVER I2CD1
#define I2C1_SDA_PIN GP26
#define I2C1_SCL_PIN GP27

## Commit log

2026-08-27 LarpBoard: Completed
    just designed the pcb and also updated the README and Journal
    [BOM_Board1_PCB1_2026-08-27.csv, SwitchPlate.dxf]
2026-09-28 Revise README for PCB and BOM details
    Updated instructions for PCB manufacturing and 3D printing, including direct source links for components in the BOM.
2026-09-28 Cleaning the Repo
    [CHERRYMX CAD_CAM KEYCAPS.stp, Cherry MX.STEP, SwitchPlate.dxf]
